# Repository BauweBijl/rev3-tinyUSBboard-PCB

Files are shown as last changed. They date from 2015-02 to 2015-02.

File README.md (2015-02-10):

# rev3-tinyUSBboard-PCB
TinyUSBboard revision 3 PCB Eagle files (single sided tht bb_1.2_rev3_tinyUSBboard)

This board design is intended to create a tinyUSBboard rev3 as a singlesided PCB with the toner transfer method.
The board allows to use both common available components and the specified (and recommended) components from the tinyUSBboard-rev3 kit.

see also:
http://matrixstorm.com/avr/tinyusbboard/

# Download and Print
Open the tinyusbboard_tht_singlesided.brd in Eagle and select the layers:

1. Bottom
2. Pads
3. Vias
4. Unrouted
5. Dimensions
6. Holes

Hit Ratsnest and print.

# Build
This board design does not come with silkscreen or other information.

To build the board properly it's best to open all layers of tinyusbboard_tht_singlesided.brd in Eagle to view placements, values etc.

Some airwires are created on the toplayer.

# Instructions
Build instructions with images can be found here:
http://wiki.bauwe.nl/TinyUSBboard/Building_TinyUSBboard_rev3_PCB

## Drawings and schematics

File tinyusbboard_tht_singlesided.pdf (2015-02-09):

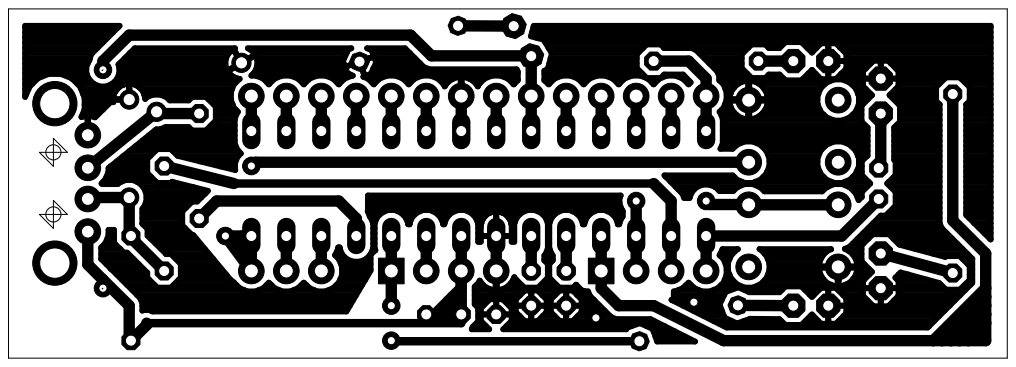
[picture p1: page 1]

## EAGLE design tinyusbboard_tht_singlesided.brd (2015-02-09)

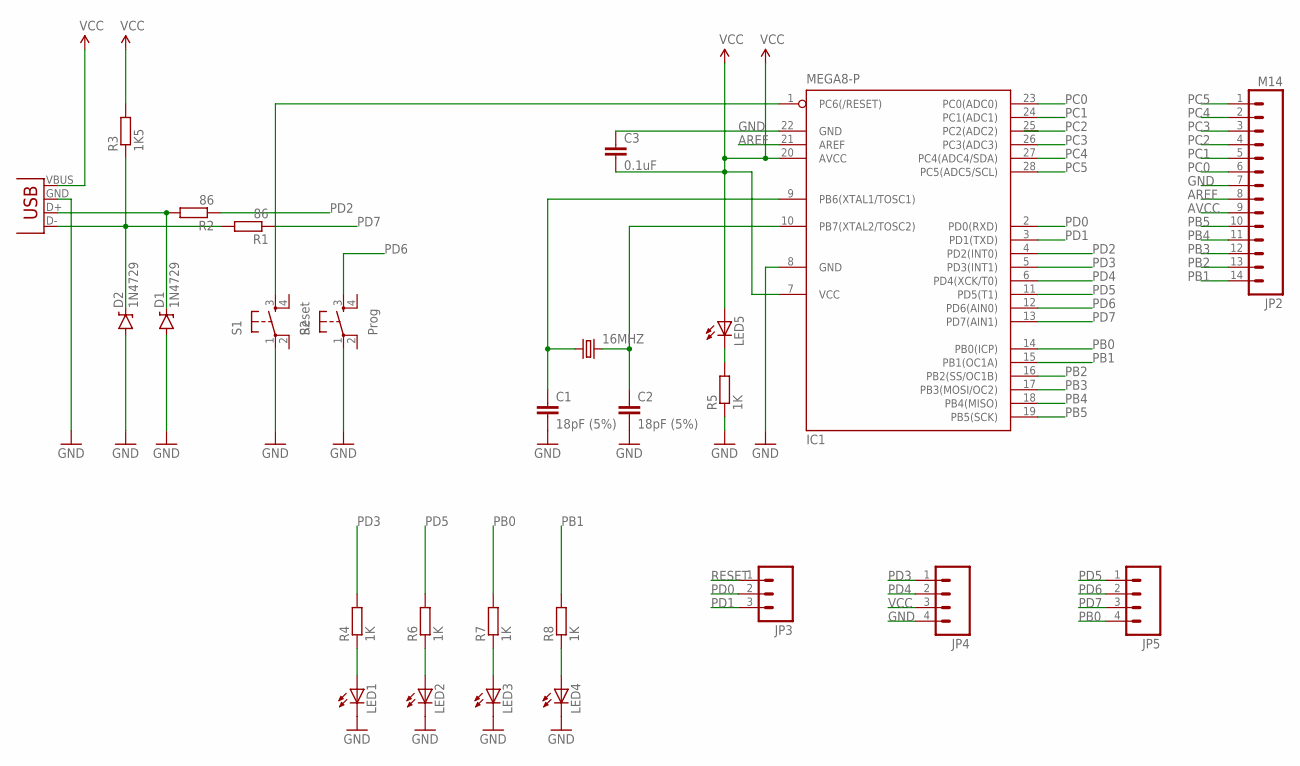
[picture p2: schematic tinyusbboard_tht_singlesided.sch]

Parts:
16MHZ: CRYSTALTC26V; TC26V
C1, C2: 18pF (5%); C025-024X044
C3: 0.1uF; C025-024X044
D1, D2: 1N4729; DIODE-ZENER
IC1: MEGA8-P; DIL28-3
JP1: USB-A-H
JP2: M14; 1X14
JP3: M03PTH; 1X03
JP4, JP5: M04PTH; 1X04
LED1, LED2, LED3, LED4, LED5: LED3MM
R1, R2: 86; 0204/7
R3: 1K5; 0204/7
R4, R5, R6, R7, R8: 1K; 0204/7
S1: Reset; TACTILE-PTH
S2: Prog; TACTILE-PTH

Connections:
AREF: IC1.21 (AREF), JP2.8
AVCC: JP2.9
D+: D1.P$1 (C), JP1.D+ (D-), R2.2
D-: D2.P$1 (C), JP1.D- (D+), R1.2, R3.1
GND: C1.2, C2.2, C3.1, D1.P$2 (A), D2.P$2 (A), IC1.8 (GND), IC1.22 (GND), JP1.GND (VBUS), JP2.7, JP4.4, LED1.K (C), LED2.K (C), LED3.K (C), LED4.K (C), R5.1, S1.1, S2.1
unnamed: LED5.K (C), R5.2
unnamed: LED1.A, R4.1
unnamed: LED2.A, R6.1
unnamed: LED3.A, R7.1
unnamed: LED4.A, R8.1
unnamed: 16MHZ.1, C1.1, IC1.9 (PB6(XTAL1/TOSC1))
unnamed: 16MHZ.2, C2.1, IC1.10 (PB7(XTAL2/TOSC2))
PB0: IC1.14 (PB0(ICP)), JP5.4, R7.2
PB1: IC1.15 (PB1(OC1A)), JP2.14, R8.2
PB2: IC1.16 (PB2(SS/OC1B)), JP2.13
PB3: IC1.17 (PB3(MOSI/OC2)), JP2.12
PB4: IC1.18 (PB4(MISO)), JP2.11
PB5: IC1.19 (PB5(SCK)), JP2.10
PC0: IC1.23 (PC0(ADC0)), JP2.6
PC1: IC1.24 (PC1(ADC1)), JP2.5
PC2: IC1.25 (PC2(ADC2)), JP2.4
PC3: IC1.26 (PC3(ADC3)), JP2.3
PC4: IC1.27 (PC4(ADC4/SDA)), JP2.2
PC5: IC1.28 (PC5(ADC5/SCL)), JP2.1
PD0: IC1.2 (PD0(RXD)), JP3.2
PD1: IC1.3 (PD1(TXD)), JP3.3
PD2: IC1.4 (PD2(INT0)), R2.1
PD3: IC1.5 (PD3(INT1)), JP4.1, R4.2
PD4: IC1.6 (PD4(XCK/T0)), JP4.2
PD5: IC1.11 (PD5(T1)), JP5.1, R6.2
PD6: IC1.12 (PD6(AIN0)), JP5.2, S2.3
PD7: IC1.13 (PD7(AIN1)), JP5.3, R1.1
RESET: IC1.1 (PC6(/RESET)), JP3.1, S1.3
VCC: C3.2, IC1.7 (VCC), IC1.20 (AVCC), JP1.VBUS (GND), JP4.3, LED5.A, R3.2

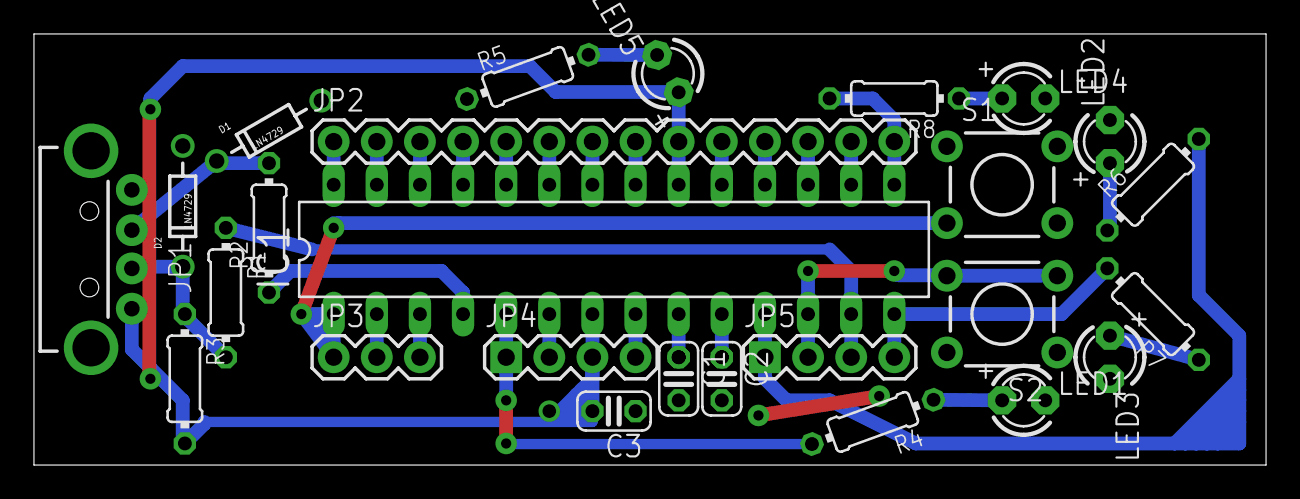
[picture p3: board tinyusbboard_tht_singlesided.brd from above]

Board: 2 copper layers, 72.6 x 25.4 mm, 27 parts (1 on the bottom side), 33 nets.

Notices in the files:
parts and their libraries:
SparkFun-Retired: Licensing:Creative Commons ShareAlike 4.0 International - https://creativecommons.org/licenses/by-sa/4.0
